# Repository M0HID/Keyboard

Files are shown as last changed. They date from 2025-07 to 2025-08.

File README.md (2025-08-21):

# K75 - A lightweight, 75% mechanical keyboard

This is a 75% keyboard fully designed by me, including the PCB, case, and firmware. It is designed to use _KMK_, a circuitpython-based firmware for keyboards! I included a rotary encoder, as well as a few "action" keys on the side of the keyboard which can be reprogrammed to anything you want, such as media controls, text controls, or any kind of shortcut you can think of!


### The PCB:
I wanted to create a challenge for myself, and so opted to use the simple _Xiao RP2040_ as the main MCU. This is however, quite limited in terms of I/O and so i had to make use of 2 MCP23017 io expanders! I also opted to use the QFP footprint on both of them which made things slightly easier to route, given the tight space but probably going to be really hard to solder :sob:




### The BOM:
| Item | Part # | Amount | Price [$] |
|:---:|---|---|---|
| 0402 SMD Diodes | C470745 | 82 | 0.60 |
| Akko cream yellow switches | https://www.aliexpress.com/item/1005007665996795.html | 82 | 27.52 |
| Purple Keycap Set | https://www.aliexpress.com/item/1005005622221680.html | 1 | 15.01 |
| Reverse Mount SK6812-Mini-E | C5149201 | 86 | 5.91 |
| Xiao RP2040 | 1597-102010428-ND | 1 | 4.68 |
| MCP23017 | C629439 | 2 | 3.03 |
| Mill-Max 0305 Hotswap Sockets | ED90584-ND | 164 | 31.42 |
| 3D printed case shipping | | 1 | 4.42 |
| PCB | | | 26.94 |
| PCB mounted Stabilisers | https://www.aliexpress.com/item/1005001632672798.html | 1 | 17.39 |
| Rotary Encoder | C470745 | 1 | 2.81 |
| WS2812B Led Sidelighting | | 1 | 5.53
| Total | | | 139.19 |

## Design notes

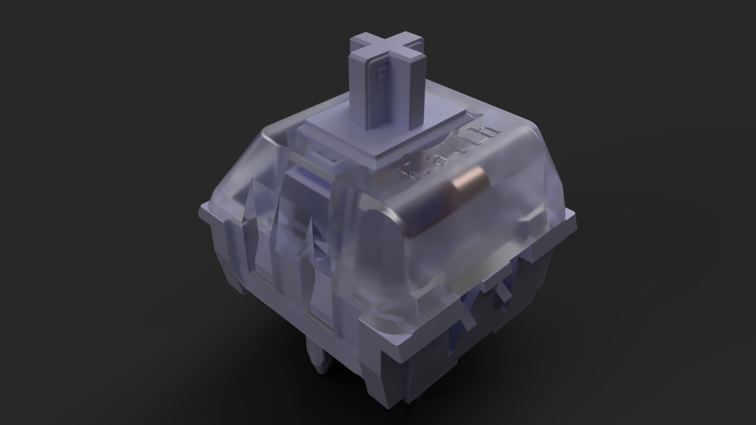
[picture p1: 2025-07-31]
pcb/kailh-polia-switch-cherry-mx-compatible-1.snapshot.1/Render.png

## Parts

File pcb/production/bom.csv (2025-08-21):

Designator | Footprint | Quantity | Value | LCSC Part #
D1, D10, D11, D12, D13, D14, D15, D16, D17, D18, D19, D2, D20, D21, D22, D23, D24, D25, D26, D27, D28, D29, D3, D30, D31, D32, D33, D34, D35, D36, D37, D38, D39, D4, D40, D41, D42, D43, D44, D45, D46, D47, D48, D49, D5, D50, D51, D52, D53, D54, D55, D56, D57, D58, D59, D6, D60, D61, D62, D63, D64, D65, D66, D67, D68, D69, D7, D70, D71, D72, D73, D74, D75, D76, D77, D78, D79, D8, D80, D81, D82, D9 | D_SOD-123 | 82 | D
D100, D101, D102, D103, D104, D105, D106, D107, D108, D109, D110, D111, D112, D113, D114, D115, D116, D117, D118, D119, D120, D121, D122, D123, D124, D125, D126, D127, D128, D129, D130, D131, D132, D133, D134, D135, D136, D137, D138, D139, D140, D141, D142, D143, D144, D145, D146, D147, D148, D149, D150, D151, D152, D153, D154, D155, D156, D157, D159, D160, D161, D162, D163, D164, D165, D166, D167, D168, D169, D83, D84, D85, D86, D87, D88, D89, D90, D91, D92, D93, D94, D95, D96, D97, D98, D99 | SK6812-MINI-E | 86 | WS2812B
SW1, SW10, SW11, SW12, SW13, SW14, SW15, SW16, SW17, SW18, SW19, SW2, SW20, SW21, SW22, SW23, SW24, SW25, SW26, SW27, SW29, SW3, SW31, SW32, SW33, SW34, SW35, SW36, SW37, SW38, SW39, SW4, SW40, SW41, SW42, SW44, SW46, SW47, SW48, SW49, SW5, SW50, SW51, SW52, SW53, SW54, SW55, SW56, SW58, SW6, SW60, SW61, SW62, SW63, SW64, SW65, SW66, SW67, SW68, SW69, SW7, SW71, SW72, SW77, SW78, SW79, SW8, SW80, SW81, SW82, SW9 | SW_Cherry_MX_1.00u_PCB | 71 | SW_Push_45deg
SW28 | SW_Cherry_MX_2.00u_PCB | 1 | SW_Push_45deg
SW30, SW43 | SW_Cherry_MX_1.50u_PCB | 2 | SW_Push_45deg
SW45, SW70 | SW_Cherry_MX_1.75u_PCB | 2 | SW_Push_45deg
SW57, SW59 | SW_Cherry_MX_2.25u_PCB | 2 | SW_Push_45deg
SW73, SW74, SW75 | SW_Cherry_MX_1.25u_PCB | 3 | SW_Push_45deg
SW76 | SW_Cherry_MX_6.25u_PCB | 1 | SW_Push_45deg
SW84 | RotaryEncoder_Alps_EC11E-Switch_Vertical_H20mm | 1 | RotaryEncoder_Switch_MP
U1 | XIAO-RP2040-DIP | 1 | MCU_Seeed_XIAO_RP2040
U2, U4 | QFN-28-1EP_6x6mm_P0.65mm_EP4.25x4.25mm | 2 | MCP23017_ML

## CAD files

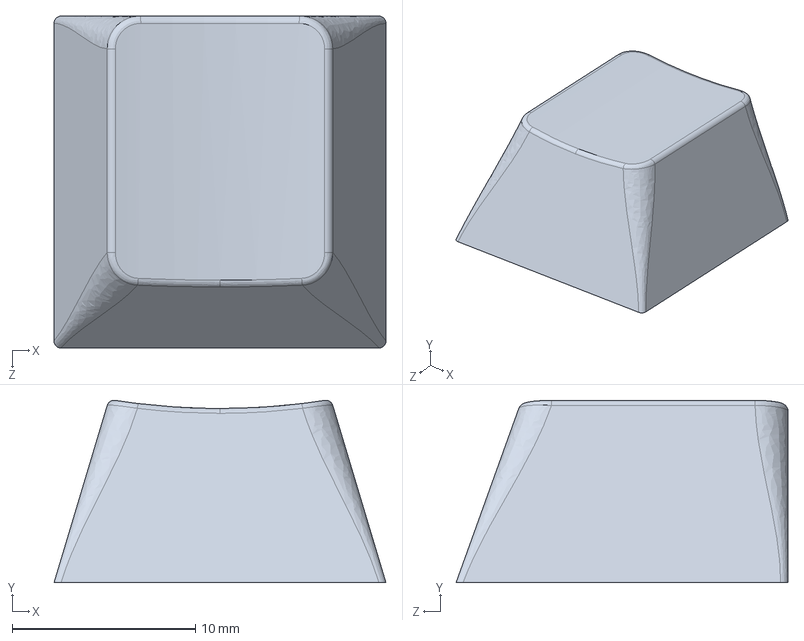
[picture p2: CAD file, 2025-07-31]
pcb/CherryMX-master/r1/r1_100.STEP
18.1 x 9.95 x 18.1 mm

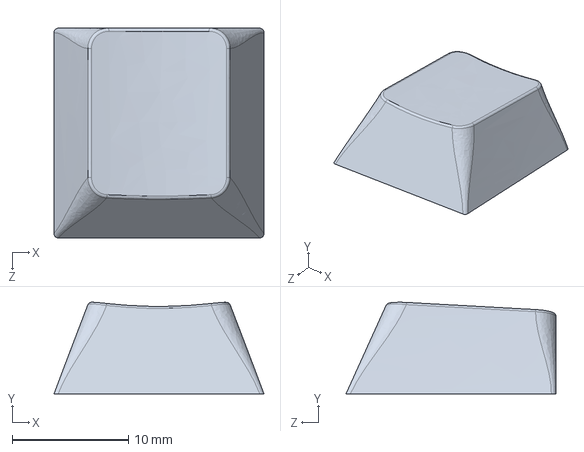
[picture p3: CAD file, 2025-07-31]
pcb/CherryMX-master/r2/r2_100.STEP
18.1 x 7.89 x 18.1 mm

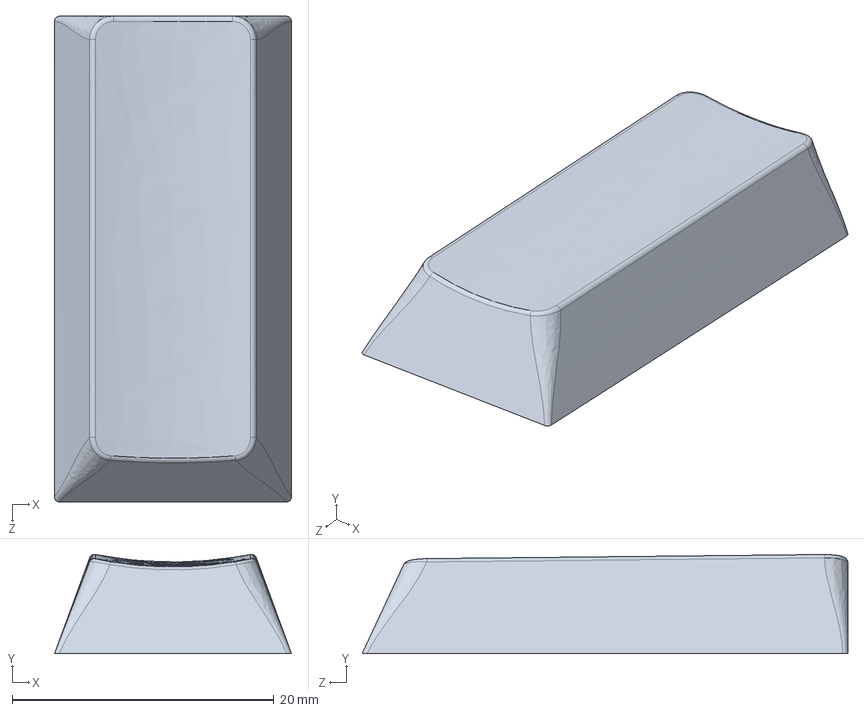
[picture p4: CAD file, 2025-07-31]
pcb/CherryMX-master/r3/r2-3_200vert.STEP
18.1 x 7.57 x 37.1 mm

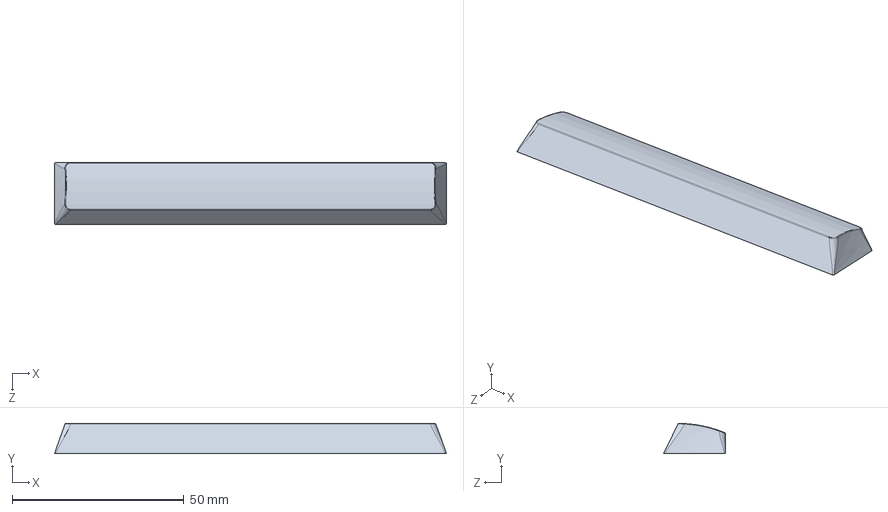
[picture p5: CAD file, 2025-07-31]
pcb/CherryMX-master/r4/r4_600.STEP
114.0 x 8.80 x 18.0 mm

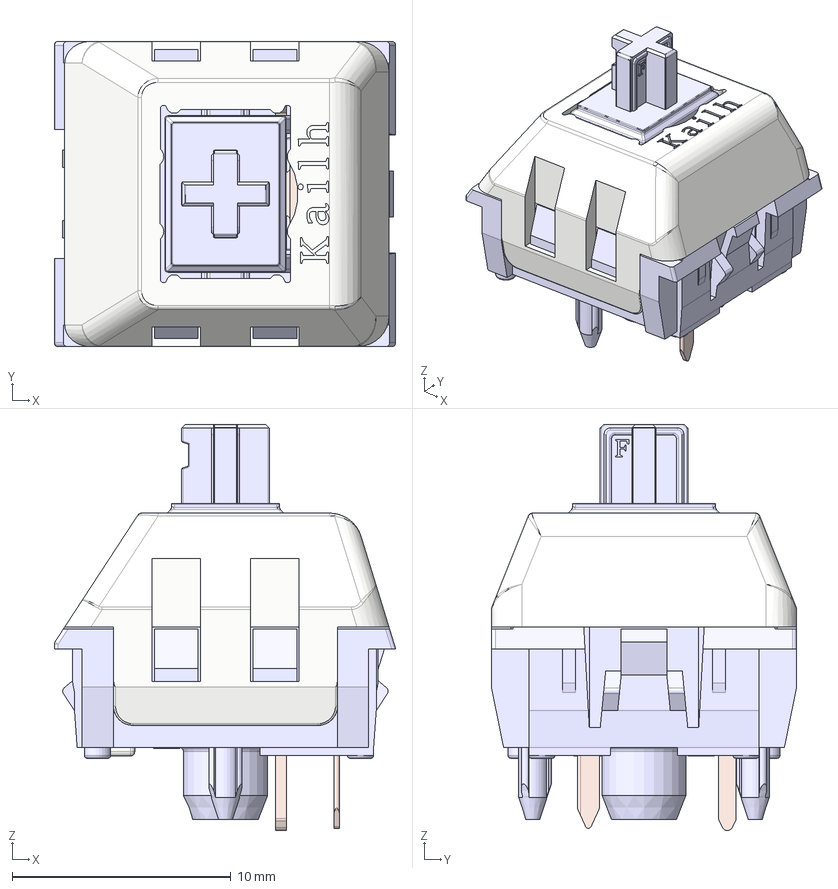
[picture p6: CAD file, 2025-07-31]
pcb/kailh-polia-switch-cherry-mx-compatible-1.snapshot.1/Kailh Polia.step
15.6 x 14.0 x 18.5 mm
Housing
ThickContact
SpringContact
Stem
Lid

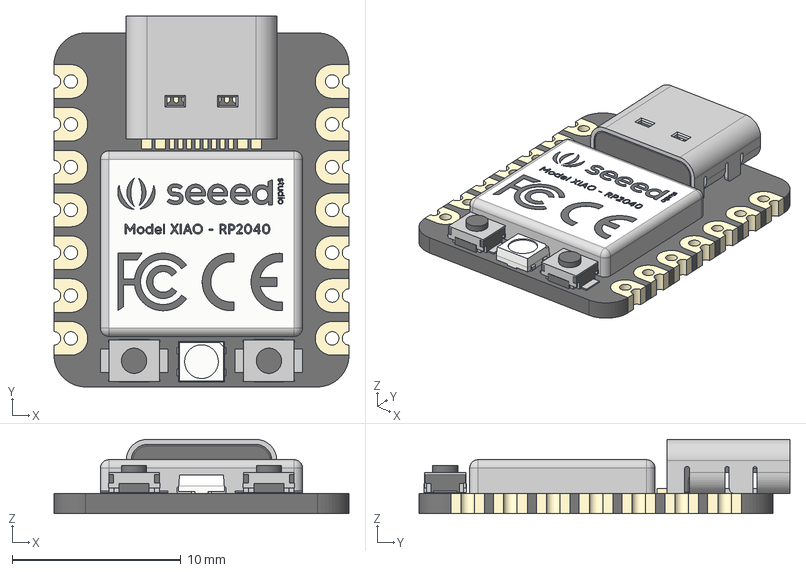
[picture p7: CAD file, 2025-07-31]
pcb/Seeed Studio XIAO RP2040 v26.step
17.5 x 22.0 x 4.40 mm
type-c v2
smd_button v3
DOUT
DIN
VSS
VDD
smd_button v3(Mirror)

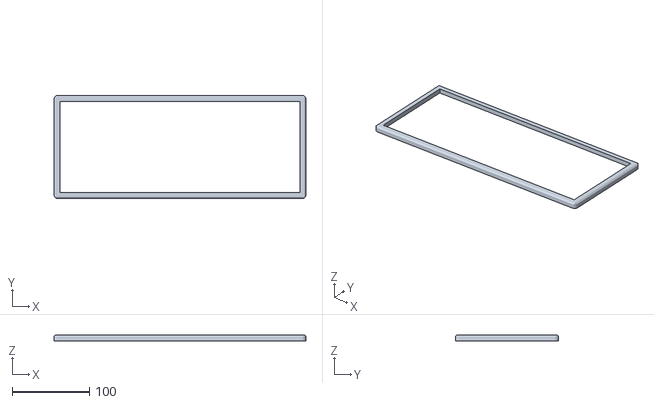
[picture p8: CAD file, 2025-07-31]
PROD/topmount.stl
326.0 x 133.6 x 7.50

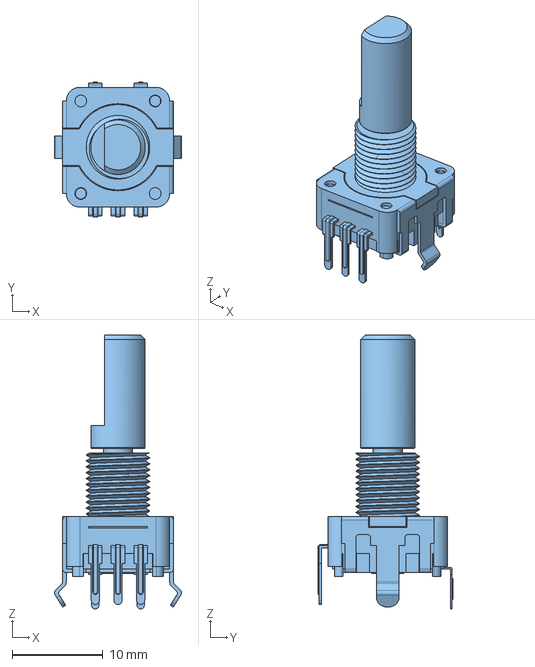
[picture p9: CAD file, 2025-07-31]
pcb/Bourns_-_PEC11R-4220F-S0024.step
14.0 x 14.9 x 30.2 mm

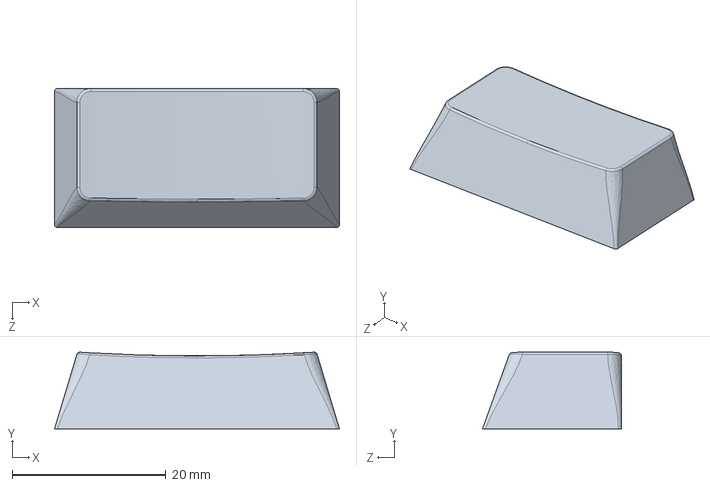
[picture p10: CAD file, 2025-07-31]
pcb/CherryMX-master/r1/r1_200.STEP
37.1 x 9.98 x 18.1 mm

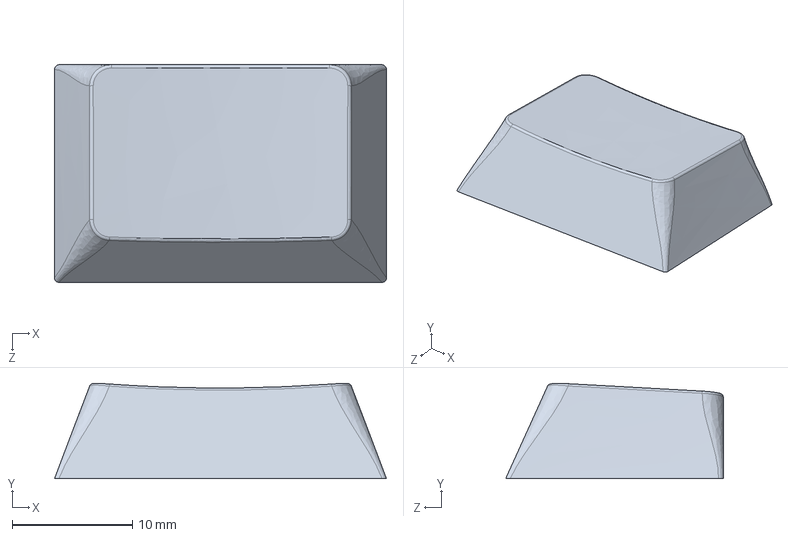
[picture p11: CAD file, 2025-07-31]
pcb/CherryMX-master/r2/r2_150.STEP
27.6 x 7.92 x 18.1 mm

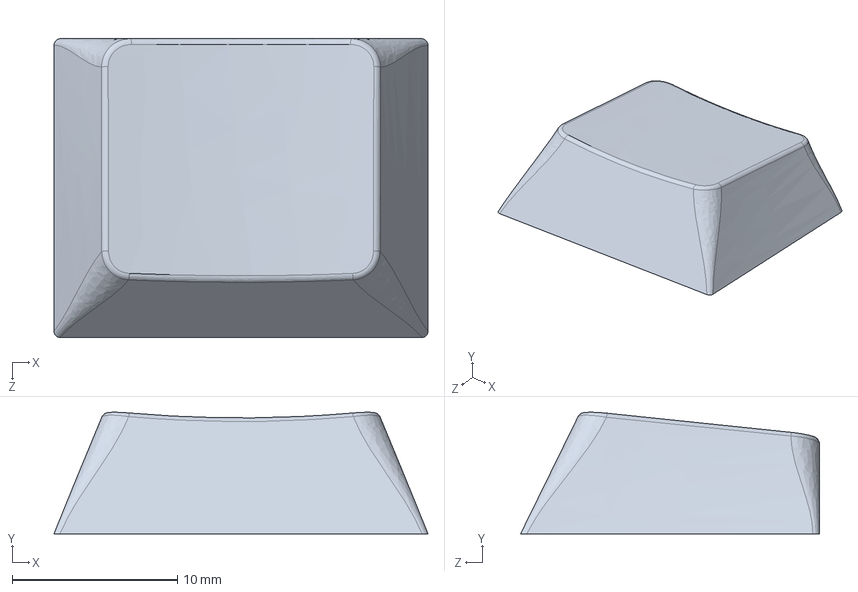
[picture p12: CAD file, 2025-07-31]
pcb/CherryMX-master/r3/r3_125.STEP
22.7 x 7.36 x 18.1 mm

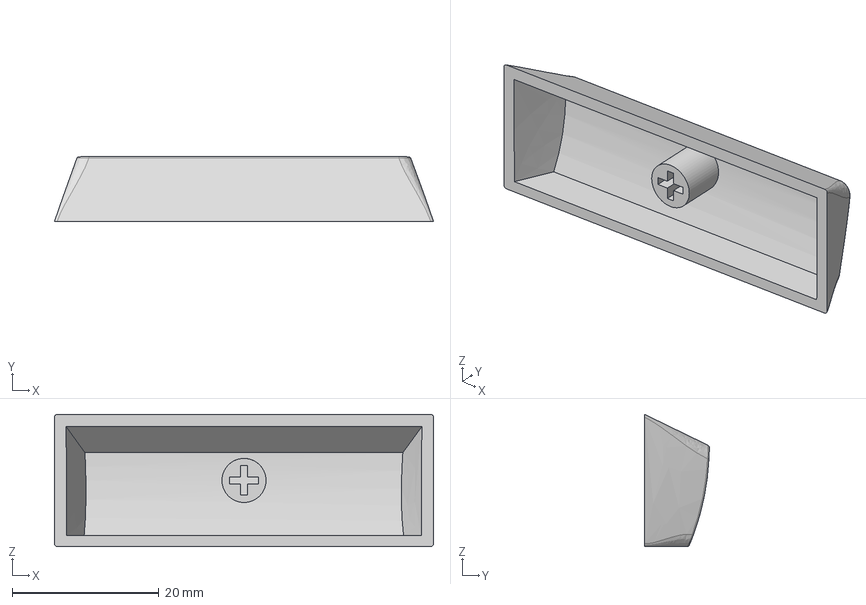
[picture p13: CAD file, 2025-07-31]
pcb/CherryMX-master/r4/r4_275C.step
51.6 x 8.80 x 18.0 mm

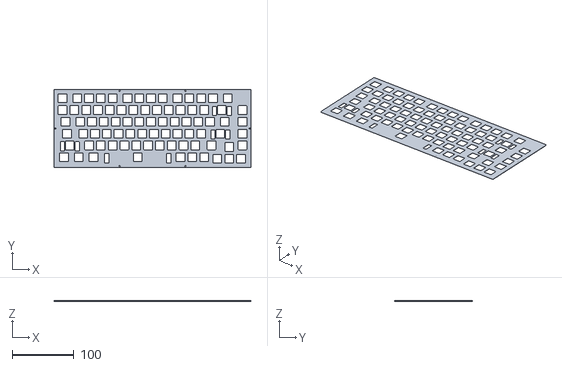
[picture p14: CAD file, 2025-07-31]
PROD/plate.stl
318.0 x 125.6 x 1.50

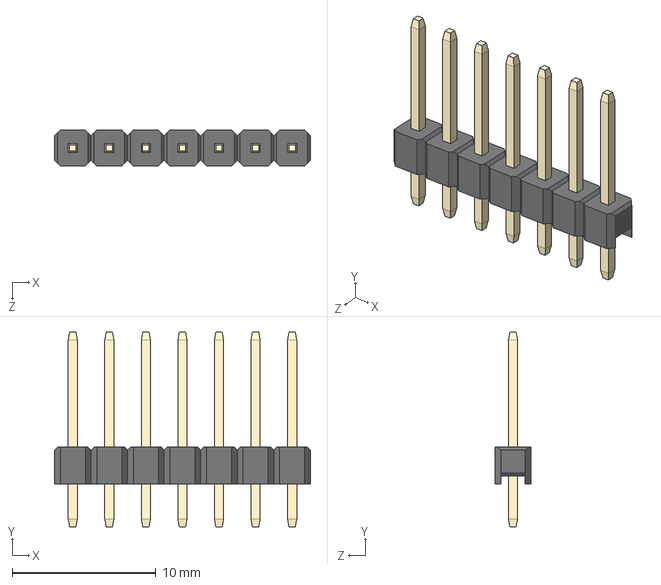
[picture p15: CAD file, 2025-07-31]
pcb/1x7 Male Pin Header.STEP
17.8 x 13.5 x 2.50 mm

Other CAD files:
pcb/CherryMX-master/r3/r3_200.STEP
pcb/CherryMX-master/r4/r4_225C.step
PROD/bottomshell.stl
pcb/CherryMX-master/r3/r3_150.STEP
pcb/CherryMX-master/r3/r3_100.STEP
pcb/CherryMX-master/r3/r3_100_bar.STEP
pcb/CherryMX-master/r3/r3_100_sculpted.STEP
pcb/CherryMX-master/r3/r3_175.STEP
pcb/CherryMX-master/r3/r3_175_stepped.STEP
pcb/CherryMX-master/r3/r3_225.STEP
pcb/CherryMX-master/r3/r3_iso.STEP
pcb/CherryMX-master/r4/r3-4_200vert.STEP
pcb/CherryMX-master/r4/r4_100.STEP
pcb/CherryMX-master/r4/r4_100C.step
pcb/CherryMX-master/r4/r4_125.STEP
pcb/CherryMX-master/r4/r4_150.STEP
pcb/CherryMX-master/r4/r4_175.STEP
pcb/CherryMX-master/r4/r4_175C.step
pcb/CherryMX-master/r4/r4_200.STEP
pcb/CherryMX-master/r4/r4_200C.step
pcb/CherryMX-master/r4/r4_225.STEP
pcb/CherryMX-master/r4/r4_275.STEP
pcb/CherryMX-master/r4/r4_300C.step
pcb/CherryMX-master/r4/r4_625.STEP
pcb/CherryMX-master/r4/r4_700.STEP

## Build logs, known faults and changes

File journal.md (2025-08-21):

---
title: "K75"
author: "@m0.hid"
description: "A 75% keyboard with per-key rgb lighting, a rotary encoder and usb-c!"
created_at: "2025-06-25"
Time Taken: 15 hours
---

### Making the schematic
Made the schematic, using 1x xiao rp2040, 1 rotary encoder, 2x i/o expanders (since the xiao itself doesnt have enough pins), and leds for each switch.
I tried doing something to make this process more automatic using hierarchal sheets but ended up just doing it all manually
Schematic:

Time += 3 hours

### Positioning all the components
Opened up the pcb editor, and put all the footprints where they're supposed to go.
I placed the xiao rp2040 underneath one of the switches on the left so it doesnt take up any extra room on the pcb. This should make it one clean board with nothing sticking out of it!  
Also i opted to use smaller 0402 smd diodes since they're smaller, hopefully i'll be able to reflow them :sob:
Started doing some of the routing as well

TIme += 2 hours

### Continue routing
I decided to modify the diode footprint a bit, so that it has a via underneath, which should hopefully make it a bit easier to route.

Finished up the rows as well

Time += 2 hours

### I/O expander
Added in one of the io expanders, underneath the enter key so it should have space to route wires to. did most of the wiring for that today.

Time += 2 hours

### the other I/O expander
Today I added in the other io expander, and started finishing up the routing. I think all the routing is done now. There wasnt much space for this one but i managed to squeeze it between the 2 function keys f4 and f5 since they have a gap between them.

Routing it was pretty difficult since there wasnt much space to fit vias or anything, so i tried re-assigning the labels in the schematic so they'd be physically closer to where they need to be 

Time += 4 hours

### Oled screen?
no

Sadly, i spent a bunch of time, trying different arrangements to fit one in, but it just wouldnt work without significant reworks (which i am not bothered to do :pray:). Maybe I'll design another kb in the future which has sone but until then, ill have to survive without one


### the 3d model!
I spent sooo long assigning the 3d models to each component, and ended up with a pretty good representation of what the kb will look like:

Time += 2 hours

And thats it for the pcb!! Moving on to the...

# the Case
Gonna try making something like this:


I made the plate using https://www.keyboard-layout-editor.com/, and then https://kbplate.ai03.com/.
Imported that in fusion, then made it 1.5mm thick and extruded the upper lip kind of thing


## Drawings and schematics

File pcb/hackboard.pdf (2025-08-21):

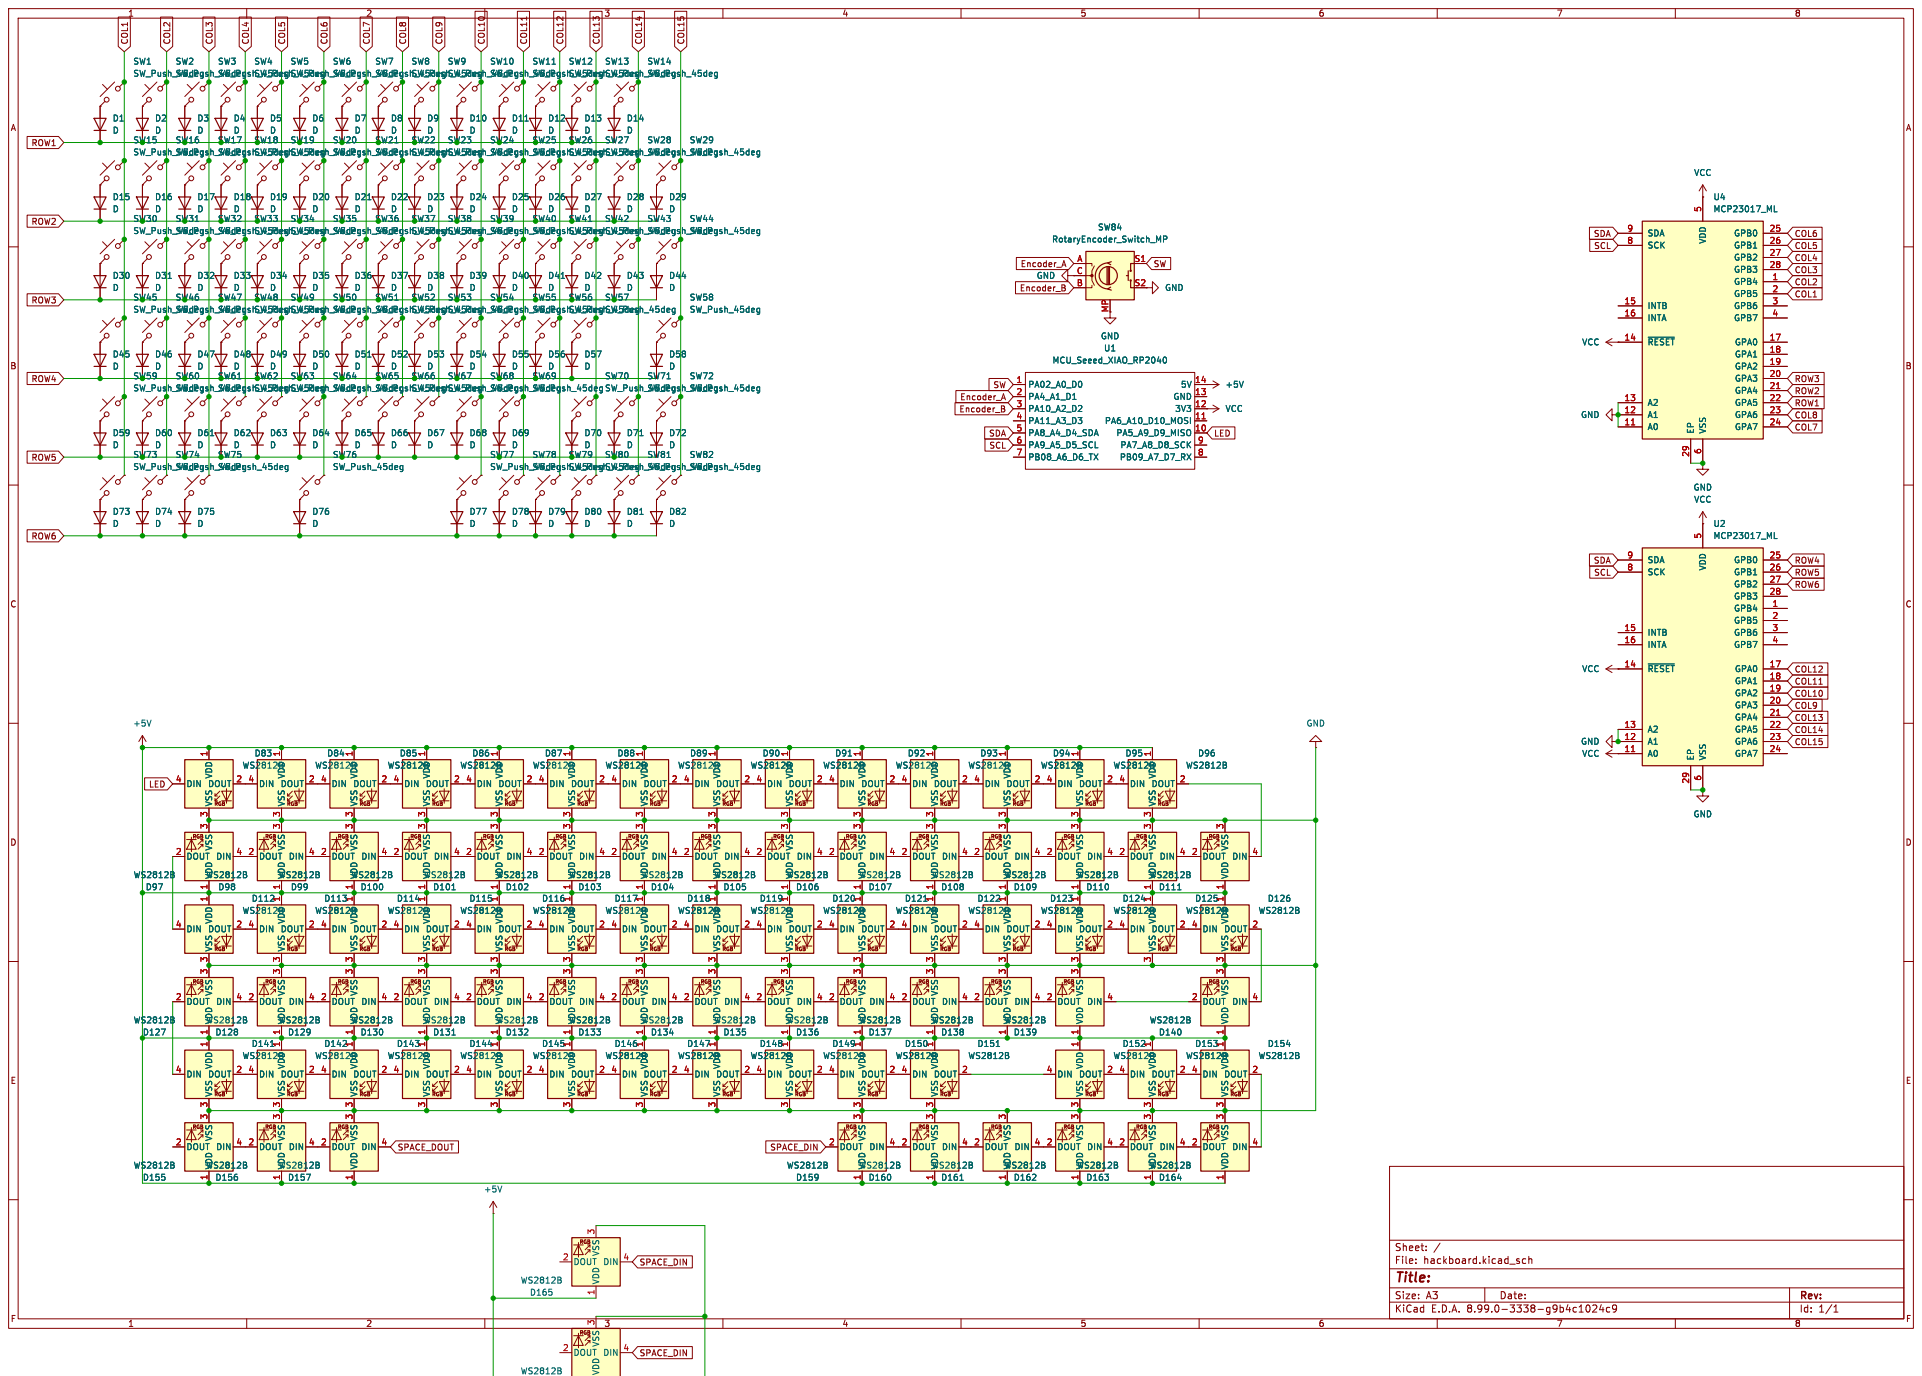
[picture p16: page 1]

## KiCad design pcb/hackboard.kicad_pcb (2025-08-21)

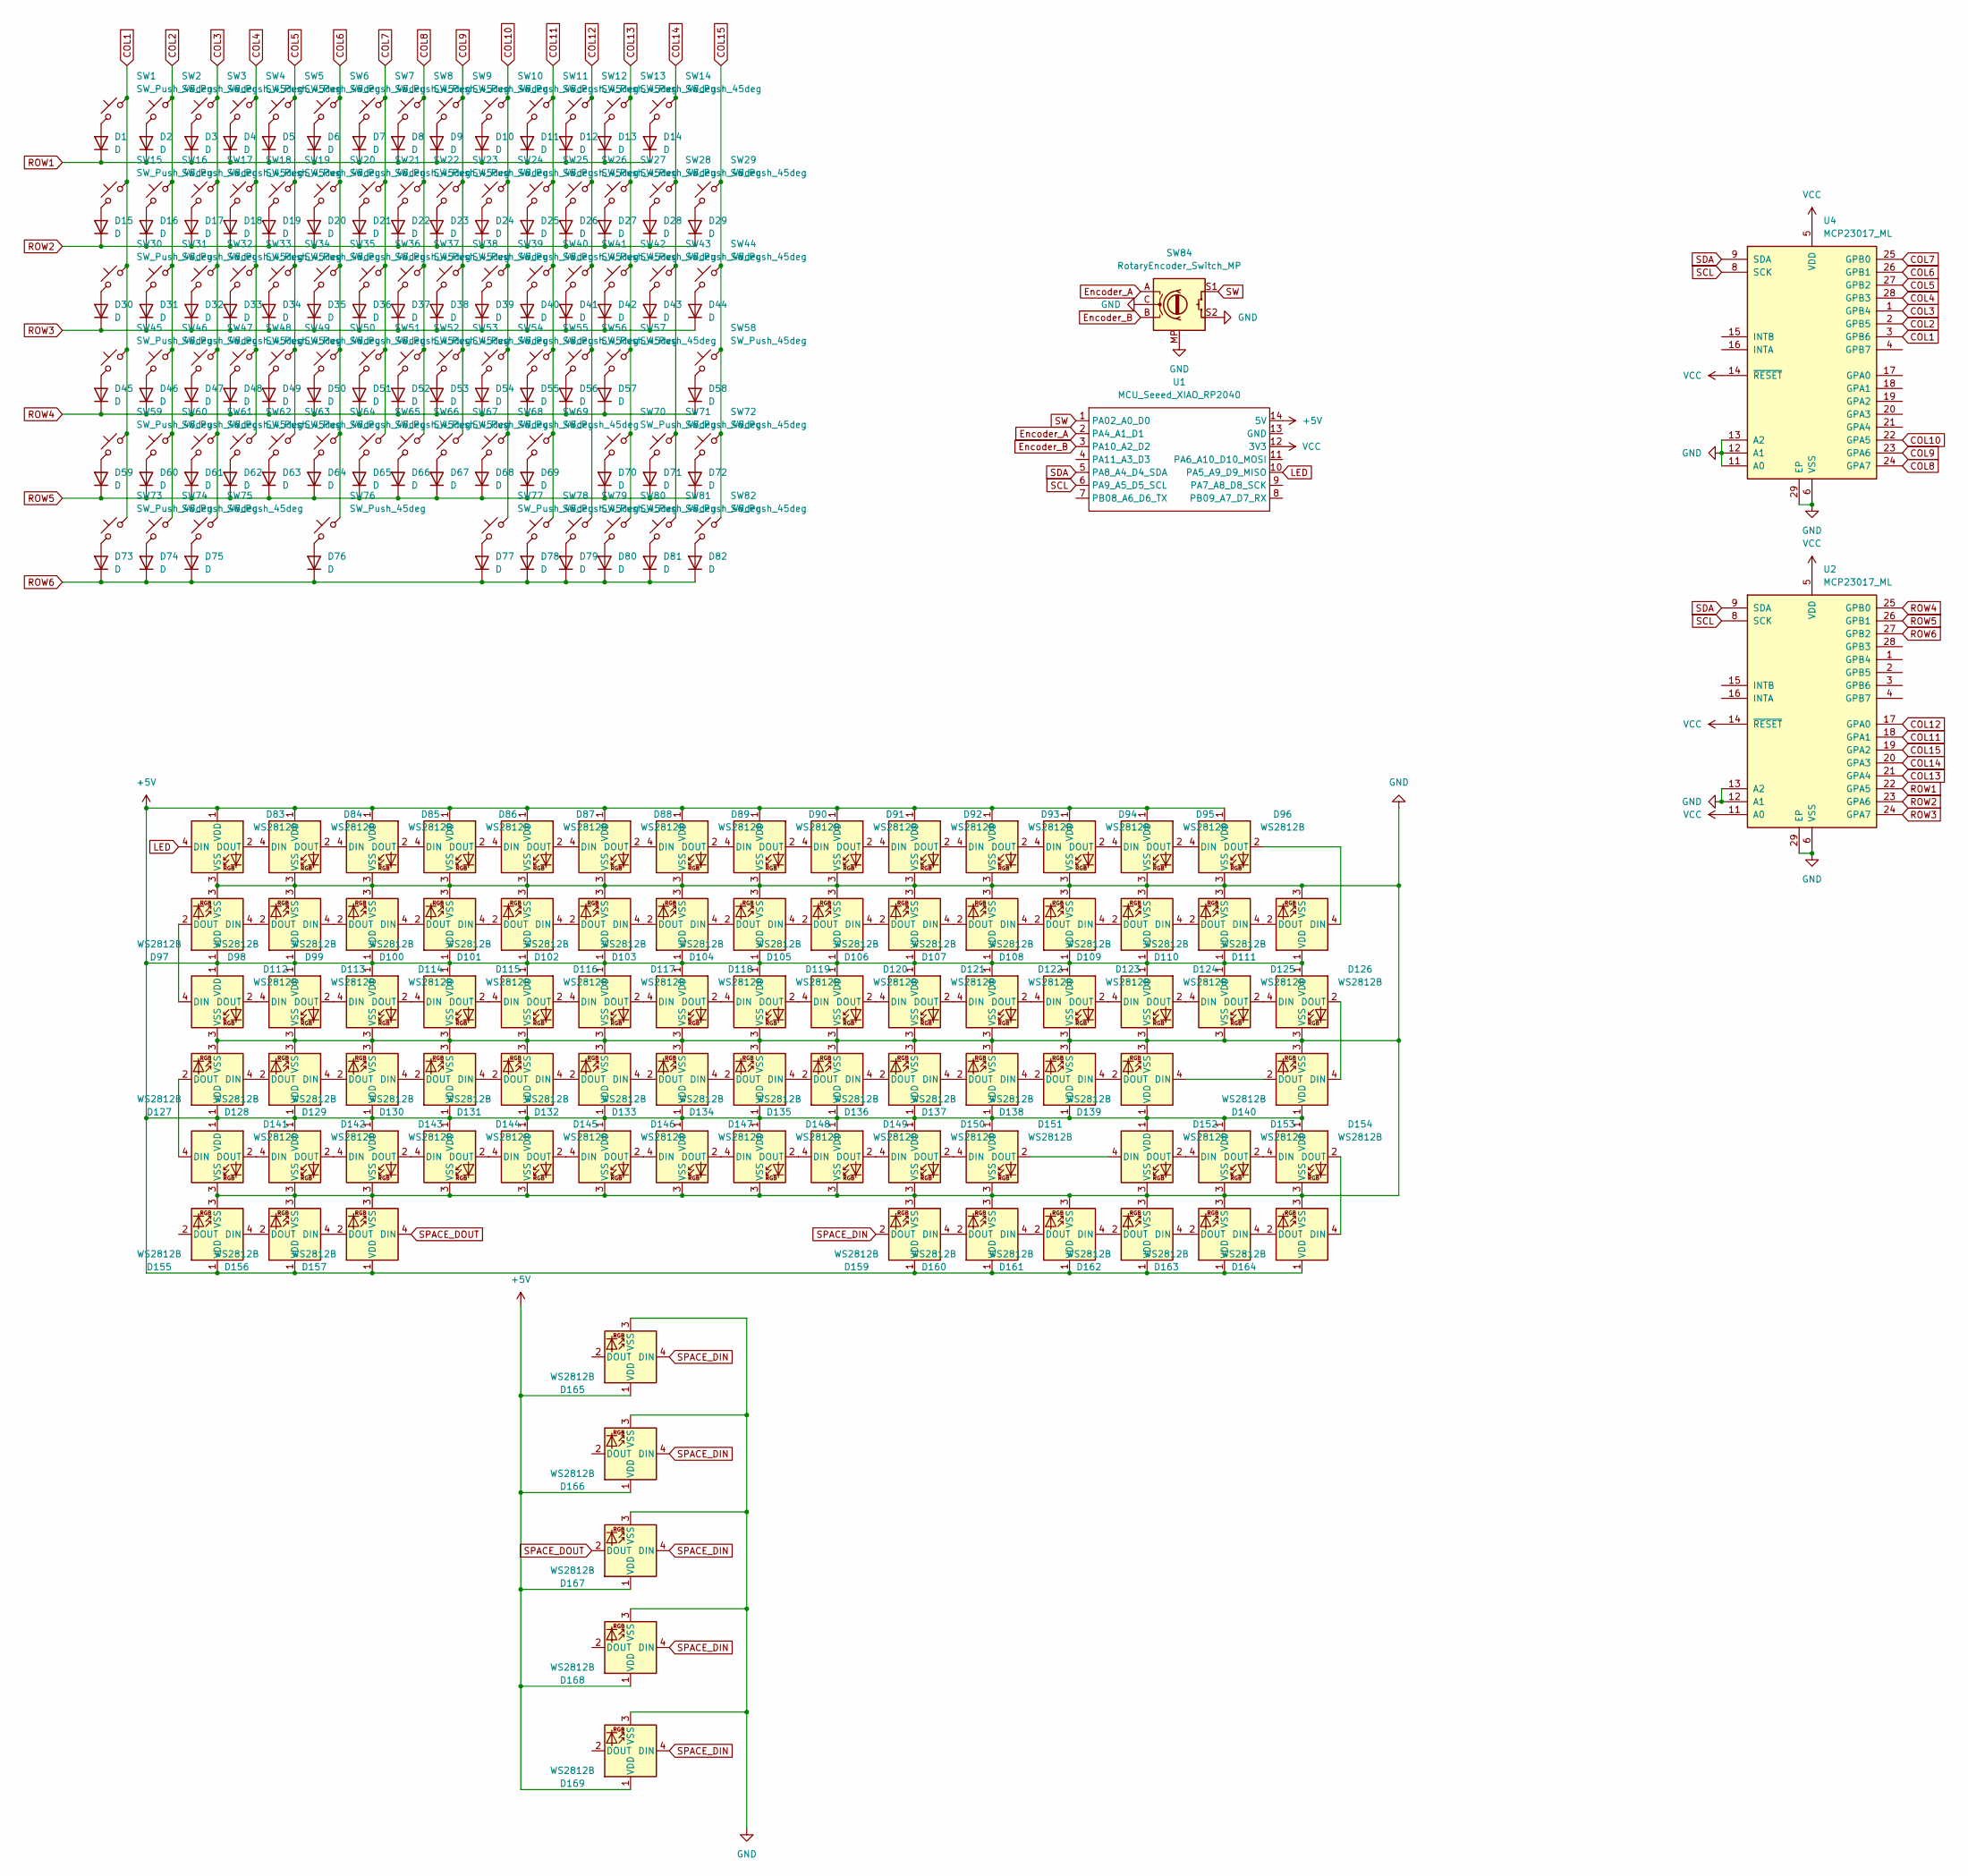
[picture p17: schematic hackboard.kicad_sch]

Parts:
D1, D2, D3, D4, D5, D6, D7, D8, D9, D10, D11, D12, D13, D14, D15, D16, D17, D18, D19, D20, D21, D22, D23, D24, D25, D26, D27, D28, D29, D30, D31, D32, D33, D34, D35, D36, D37, D38, D39, D40, D41, D42, D43, D44, D45, D46, D47, D48, D49, D50, D51, D52, D53, D54, D55, D56, D57, D58, D59, D60, D61, D62, D63, D64, D65, D66, D67, D68, D69, D70, D71, D72, D73, D74, D75, D76, D77, D78, D79, D80, D81, D82: D; D_SOD-123
D83, D84, D85, D86, D87, D88, D89, D90, D91, D92, D93, D94, D95, D96, D97, D98, D99, D100, D101, D102, D103, D104, D105, D106, D107, D108, D109, D110, D111, D112, D113, D114, D115, D116, D117, D118, D119, D120, D121, D122, D123, D124, D125, D126, D127, D128, D129, D130, D131, D132, D133, D134, D135, D136, D137, D138, D139, D140, D141, D142, D143, D144, D145, D146, D147, D148, D149, D150, D151, D152, D153, D154, D155, D156, D157, D159, D160, D161, D162, D163, D164, D165, D166, D167, D168, D169: WS2812B; SK6812-MINI-E
SW1, SW2, SW3, SW4, SW5, SW6, SW7, SW8, SW9, SW10, SW11, SW12, SW13, SW14, SW15, SW16, SW17, SW18, SW19, SW20, SW21, SW22, SW23, SW24, SW25, SW26, SW27, SW29, SW31, SW32, SW33, SW34, SW35, SW36, SW37, SW38, SW39, SW40, SW41, SW42, SW44, SW46, SW47, SW48, SW49, SW50, SW51, SW52, SW53, SW54, SW55, SW56, SW58, SW60, SW61, SW62, SW63, SW64, SW65, SW66, SW67, SW68, SW69, SW71, SW72, SW77, SW78, SW79, SW80, SW81, SW82: SW_Push_45deg; SW_Cherry_MX_1.00u_PCB
SW28: SW_Push_45deg; SW_Cherry_MX_2.00u_PCB
SW30, SW43: SW_Push_45deg; SW_Cherry_MX_1.50u_PCB
SW45, SW70: SW_Push_45deg; SW_Cherry_MX_1.75u_PCB
SW57, SW59: SW_Push_45deg; SW_Cherry_MX_2.25u_PCB
SW73, SW74, SW75: SW_Push_45deg; SW_Cherry_MX_1.25u_PCB
SW76: SW_Push_45deg; SW_Cherry_MX_6.25u_PCB
SW84: RotaryEncoder_Switch_MP; RotaryEncoder_Alps_EC11E-Switch_Vertical_H20mm
U1: MCU_Seeed_XIAO_RP2040; XIAO-RP2040-DIP
U2, U4: MCP23017_ML; QFN-28-1EP_6x6mm_P0.65mm_EP4.25x4.25mm

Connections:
+5V: D83.1 (VDD), D84.1 (VDD), D85.1 (VDD), D86.1 (VDD), D87.1 (VDD), D88.1 (VDD), D89.1 (VDD), D90.1 (VDD), D91.1 (VDD), D92.1 (VDD), D93.1 (VDD), D94.1 (VDD), D95.1 (VDD), D96.1 (VDD), D97.1 (VDD), D98.1 (VDD), D99.1 (VDD), D100.1 (VDD), D101.1 (VDD), D102.1 (VDD), D103.1 (VDD), D104.1 (VDD), D105.1 (VDD), D106.1 (VDD), D107.1 (VDD), D108.1 (VDD), D109.1 (VDD), D110.1 (VDD), D111.1 (VDD), D112.1 (VDD), D113.1 (VDD), D114.1 (VDD), D115.1 (VDD), D116.1 (VDD), D117.1 (VDD), D118.1 (VDD), D119.1 (VDD), D120.1 (VDD), D121.1 (VDD), D122.1 (VDD), D123.1 (VDD), D124.1 (VDD), D125.1 (VDD), D126.1 (VDD), D127.1 (VDD), D128.1 (VDD), D129.1 (VDD), D130.1 (VDD), D131.1 (VDD), D132.1 (VDD), D133.1 (VDD), D134.1 (VDD), D135.1 (VDD), D136.1 (VDD), D137.1 (VDD), D138.1 (VDD), D139.1 (VDD), D140.1 (VDD), D141.1 (VDD), D142.1 (VDD), D143.1 (VDD), D144.1 (VDD), D145.1 (VDD), D146.1 (VDD), D147.1 (VDD), D148.1 (VDD), D149.1 (VDD), D150.1 (VDD), D151.1 (VDD), D152.1 (VDD), D153.1 (VDD), D154.1 (VDD), D155.1 (VDD), D156.1 (VDD), D157.1 (VDD), D159.1 (VDD), D160.1 (VDD), D161.1 (VDD), D162.1 (VDD), D163.1 (VDD), D164.1 (VDD), D165.1 (VDD), D166.1 (VDD), D167.1 (VDD), D168.1 (VDD), D169.1 (VDD), U1.14 (5V)
COL1: SW1.2, SW15.2, SW30.2, SW45.2, SW59.2, SW73.2, U4.3 (GPB6)
COL2: SW2.2, SW16.2, SW31.2, SW46.2, SW60.2, SW74.2, U4.2 (GPB5)
COL3: SW3.2, SW17.2, SW32.2, SW47.2, SW61.2, SW75.2, U4.1 (GPB4)
COL4: SW4.2, SW18.2, SW33.2, SW48.2, SW62.2, U4.28 (GPB3)
COL5: SW5.2, SW19.2, SW34.2, SW49.2, SW63.2, U4.27 (GPB2)
COL6: SW6.2, SW20.2, SW35.2, SW50.2, SW64.2, SW76.2, U4.26 (GPB1)
COL7: SW7.2, SW21.2, SW36.2, SW51.2, SW65.2, U4.25 (GPB0)
COL8: SW8.2, SW22.2, SW37.2, SW52.2, SW66.2, U4.24 (GPA7)
COL9: SW9.2, SW23.2, SW38.2, SW53.2, SW67.2, U4.23 (GPA6)
COL10: SW10.2, SW24.2, SW39.2, SW54.2, SW68.2, SW77.2, U4.22 (GPA5)
COL11: SW11.2, SW25.2, SW40.2, SW55.2, SW69.2, SW78.2, U2.18 (GPA1)
COL12: SW12.2, SW26.2, SW41.2, SW56.2, SW79.2, U2.17 (GPA0)
COL13: SW13.2, SW27.2, SW42.2, SW57.2, SW70.2, SW80.2, U2.21 (GPA4)
COL14: SW14.2, SW28.2, SW43.2, SW71.2, SW81.2, U2.20 (GPA3)
COL15: SW29.2, SW44.2, SW58.2, SW72.2, SW82.2, U2.19 (GPA2)
Encoder_A: SW84.A, U1.2 (PA4_A1_D1)
Encoder_B: SW84.B, U1.3 (PA10_A2_D2)
GND: D83.3 (VSS), D84.3 (VSS), D85.3 (VSS), D86.3 (VSS), D87.3 (VSS), D88.3 (VSS), D89.3 (VSS), D90.3 (VSS), D91.3 (VSS), D92.3 (VSS), D93.3 (VSS), D94.3 (VSS), D95.3 (VSS), D96.3 (VSS), D97.3 (VSS), D98.3 (VSS), D99.3 (VSS), D100.3 (VSS), D101.3 (VSS), D102.3 (VSS), D103.3 (VSS), D104.3 (VSS), D105.3 (VSS), D106.3 (VSS), D107.3 (VSS), D108.3 (VSS), D109.3 (VSS), D110.3 (VSS), D111.3 (VSS), D112.3 (VSS), D113.3 (VSS), D114.3 (VSS), D115.3 (VSS), D116.3 (VSS), D117.3 (VSS), D118.3 (VSS), D119.3 (VSS), D120.3 (VSS), D121.3 (VSS), D122.3 (VSS), D123.3 (VSS), D124.3 (VSS), D125.3 (VSS), D126.3 (VSS), D127.3 (VSS), D128.3 (VSS), D129.3 (VSS), D130.3 (VSS), D131.3 (VSS), D132.3 (VSS), D133.3 (VSS), D134.3 (VSS), D135.3 (VSS), D136.3 (VSS), D137.3 (VSS), D138.3 (VSS), D139.3 (VSS), D140.3 (VSS), D141.3 (VSS), D142.3 (VSS), D143.3 (VSS), D144.3 (VSS), D145.3 (VSS), D146.3 (VSS), D147.3 (VSS), D148.3 (VSS), D149.3 (VSS), D150.3 (VSS), D151.3 (VSS), D152.3 (VSS), D153.3 (VSS), D154.3 (VSS), D155.3 (VSS), D156.3 (VSS), D157.3 (VSS), D159.3 (VSS), D160.3 (VSS), D161.3 (VSS), D162.3 (VSS), D163.3 (VSS), D164.3 (VSS), D165.3 (VSS), D166.3 (VSS), D167.3 (VSS), D168.3 (VSS), D169.3 (VSS), SW84.C, SW84.MP, SW84.S2, U2.6 (VSS), U2.12 (A1), U2.13 (A2), U2.29 (EP), U4.6 (VSS), U4.11 (A0), U4.12 (A1), U4.13 (A2), U4.29 (EP)
LED: D83.4 (DIN), U1.10 (PA5_A9_D9_MISO)
unnamed: D1.2 (A), SW1.1
unnamed: D2.2 (A), SW2.1
unnamed: D3.2 (A), SW3.1
unnamed: D4.2 (A), SW4.1
unnamed: D5.2 (A), SW5.1
unnamed: D6.2 (A), SW6.1
unnamed: D7.2 (A), SW7.1
unnamed: D8.2 (A), SW8.1
unnamed: D9.2 (A), SW9.1
unnamed: D10.2 (A), SW10.1
unnamed: D11.2 (A), SW11.1
unnamed: D12.2 (A), SW12.1
unnamed: D13.2 (A), SW13.1
unnamed: D14.2 (A), SW14.1
unnamed: D15.2 (A), SW15.1
unnamed: D16.2 (A), SW16.1
unnamed: D17.2 (A), SW17.1
unnamed: D18.2 (A), SW18.1
unnamed: D19.2 (A), SW19.1
unnamed: D20.2 (A), SW20.1
unnamed: D21.2 (A), SW21.1
unnamed: D22.2 (A), SW22.1
unnamed: D23.2 (A), SW23.1
unnamed: D24.2 (A), SW24.1
unnamed: D25.2 (A), SW25.1
unnamed: D26.2 (A), SW26.1
unnamed: D27.2 (A), SW27.1
unnamed: D28.2 (A), SW28.1
unnamed: D29.2 (A), SW29.1
unnamed: D30.2 (A), SW30.1
unnamed: D31.2 (A), SW31.1
unnamed: D32.2 (A), SW32.1
unnamed: D33.2 (A), SW33.1
unnamed: D34.2 (A), SW34.1
unnamed: D35.2 (A), SW35.1
unnamed: D36.2 (A), SW36.1
unnamed: D37.2 (A), SW37.1
unnamed: D38.2 (A), SW38.1
unnamed: D39.2 (A), SW39.1
unnamed: D40.2 (A), SW40.1
unnamed: D41.2 (A), SW41.1
unnamed: D42.2 (A), SW42.1
unnamed: D43.2 (A), SW43.1
unnamed: D44.2 (A), SW44.1
unnamed: D45.2 (A), SW45.1
unnamed: D46.2 (A), SW46.1
unnamed: D47.2 (A), SW47.1
unnamed: D48.2 (A), SW48.1
unnamed: D49.2 (A), SW49.1
unnamed: D50.2 (A), SW50.1
unnamed: D51.2 (A), SW51.1
unnamed: D52.2 (A), SW52.1
unnamed: D53.2 (A), SW53.1
unnamed: D54.2 (A), SW54.1
unnamed: D55.2 (A), SW55.1
unnamed: D56.2 (A), SW56.1
unnamed: D57.2 (A), SW57.1
unnamed: D58.2 (A), SW58.1
unnamed: D59.2 (A), SW59.1
unnamed: D60.2 (A), SW60.1
unnamed: D61.2 (A), SW61.1
unnamed: D62.2 (A), SW62.1
unnamed: D63.2 (A), SW63.1
unnamed: D64.2 (A), SW64.1
unnamed: D65.2 (A), SW65.1
unnamed: D66.2 (A), SW66.1
unnamed: D67.2 (A), SW67.1
unnamed: D68.2 (A), SW68.1
unnamed: D69.2 (A), SW69.1
unnamed: D70.2 (A), SW70.1
unnamed: D71.2 (A), SW71.1
unnamed: D72.2 (A), SW72.1
unnamed: D73.2 (A), SW73.1
unnamed: D74.2 (A), SW74.1
unnamed: D75.2 (A), SW75.1
unnamed: D76.2 (A), SW76.1
unnamed: D77.2 (A), SW77.1
unnamed: D78.2 (A), SW78.1
unnamed: D79.2 (A), SW79.1
unnamed: D80.2 (A), SW80.1
unnamed: D81.2 (A), SW81.1
unnamed: D82.2 (A), SW82.1
unnamed: D83.2 (DOUT), D84.4 (DIN)
unnamed: D84.2 (DOUT), D85.4 (DIN)
unnamed: D85.2 (DOUT), D86.4 (DIN)
unnamed: D86.2 (DOUT), D87.4 (DIN)
unnamed: D87.2 (DOUT), D88.4 (DIN)
unnamed: D88.2 (DOUT), D89.4 (DIN)
unnamed: D89.2 (DOUT), D90.4 (DIN)
unnamed: D90.2 (DOUT), D91.4 (DIN)
unnamed: D91.2 (DOUT), D92.4 (DIN)
unnamed: D92.2 (DOUT), D93.4 (DIN)
unnamed: D93.2 (DOUT), D94.4 (DIN)
unnamed: D94.2 (DOUT), D95.4 (DIN)
unnamed: D95.2 (DOUT), D96.4 (DIN)
unnamed: D97.4 (DIN), D98.2 (DOUT)
unnamed: D98.4 (DIN), D99.2 (DOUT)
unnamed: D100.4 (DIN), D101.2 (DOUT)
unnamed: D99.4 (DIN), D100.2 (DOUT)
unnamed: D101.4 (DIN), D102.2 (DOUT)
unnamed: D102.4 (DIN), D103.2 (DOUT)
unnamed: D103.4 (DIN), D104.2 (DOUT)
unnamed: D104.4 (DIN), D105.2 (DOUT)
unnamed: D105.4 (DIN), D106.2 (DOUT)
unnamed: D106.4 (DIN), D107.2 (DOUT)
unnamed: D107.4 (DIN), D108.2 (DOUT)
unnamed: D108.4 (DIN), D109.2 (DOUT)
unnamed: D109.4 (DIN), D110.2 (DOUT)
unnamed: D110.4 (DIN), D111.2 (DOUT)
unnamed: D96.2 (DOUT), D111.4 (DIN)
unnamed: D97.2 (DOUT), D112.4 (DIN)
unnamed: D112.2 (DOUT), D113.4 (DIN)
unnamed: D113.2 (DOUT), D114.4 (DIN)
unnamed: D114.2 (DOUT), D115.4 (DIN)
unnamed: D115.2 (DOUT), D116.4 (DIN)
unnamed: D116.2 (DOUT), D117.4 (DIN)
unnamed: D117.2 (DOUT), D118.4 (DIN)
unnamed: D118.2 (DOUT), D119.4 (DIN)
unnamed: D119.2 (DOUT), D120.4 (DIN)
unnamed: D120.2 (DOUT), D121.4 (DIN)
unnamed: D121.2 (DOUT), D122.4 (DIN)
unnamed: D122.2 (DOUT), D123.4 (DIN)
unnamed: D123.2 (DOUT), D124.4 (DIN)
unnamed: D124.2 (DOUT), D125.4 (DIN)
unnamed: D125.2 (DOUT), D126.4 (DIN)
unnamed: D126.2 (DOUT), D140.4 (DIN)
unnamed: D127.4 (DIN), D128.2 (DOUT)
unnamed: D127.2 (DOUT), D141.4 (DIN)
unnamed: D128.4 (DIN), D129.2 (DOUT)
unnamed: D129.4 (DIN), D130.2 (DOUT)
unnamed: D130.4 (DIN), D131.2 (DOUT)
unnamed: D131.4 (DIN), D132.2 (DOUT)
unnamed: D132.4 (DIN), D133.2 (DOUT)
unnamed: D133.4 (DIN), D134.2 (DOUT)
unnamed: D134.4 (DIN), D135.2 (DOUT)
unnamed: D135.4 (DIN), D136.2 (DOUT)
unnamed: D136.4 (DIN), D137.2 (DOUT)
unnamed: D137.4 (DIN), D138.2 (DOUT)
unnamed: D138.4 (DIN), D139.2 (DOUT)
unnamed: D139.4 (DIN), D140.2 (DOUT)
unnamed: D141.2 (DOUT), D142.4 (DIN)
unnamed: D142.2 (DOUT), D143.4 (DIN)
unnamed: D143.2 (DOUT), D144.4 (DIN)
unnamed: D144.2 (DOUT), D145.4 (DIN)
unnamed: D145.2 (DOUT), D146.4 (DIN)
unnamed: D146.2 (DOUT), D147.4 (DIN)
unnamed: D147.2 (DOUT), D148.4 (DIN)
unnamed: D148.2 (DOUT), D149.4 (DIN)
unnamed: D149.2 (DOUT), D150.4 (DIN)
unnamed: D150.2 (DOUT), D151.4 (DIN)
unnamed: D151.2 (DOUT), D152.4 (DIN)
unnamed: D152.2 (DOUT), D153.4 (DIN)
unnamed: D153.2 (DOUT), D154.4 (DIN)
unnamed: D154.2 (DOUT), D164.4 (DIN)
unnamed: D155.4 (DIN), D156.2 (DOUT)
unnamed: D156.4 (DIN), D157.2 (DOUT)
unnamed: D159.4 (DIN), D160.2 (DOUT)
unnamed: D160.4 (DIN), D161.2 (DOUT)
unnamed: D161.4 (DIN), D162.2 (DOUT)
unnamed: D162.4 (DIN), D163.2 (DOUT)
unnamed: D163.4 (DIN), D164.2 (DOUT)
ROW1: D1.1 (K), D2.1 (K), D3.1 (K), D4.1 (K), D5.1 (K), D6.1 (K), D7.1 (K), D8.1 (K), D9.1 (K), D10.1 (K), D11.1 (K), D12.1 (K), D13.1 (K), D14.1 (K), U2.22 (GPA5)
ROW2: D15.1 (K), D16.1 (K), D17.1 (K), D18.1 (K), D19.1 (K), D20.1 (K), D21.1 (K), D22.1 (K), D23.1 (K), D24.1 (K), D25.1 (K), D26.1 (K), D27.1 (K), D28.1 (K), D29.1 (K), U2.23 (GPA6)
ROW3: D30.1 (K), D31.1 (K), D32.1 (K), D33.1 (K), D34.1 (K), D35.1 (K), D36.1 (K), D37.1 (K), D38.1 (K), D39.1 (K), D40.1 (K), D41.1 (K), D42.1 (K), D43.1 (K), D44.1 (K), U2.24 (GPA7)
ROW4: D45.1 (K), D46.1 (K), D47.1 (K), D48.1 (K), D49.1 (K), D50.1 (K), D51.1 (K), D52.1 (K), D53.1 (K), D54.1 (K), D55.1 (K), D56.1 (K), D57.1 (K), D58.1 (K), U2.25 (GPB0)
ROW5: D59.1 (K), D60.1 (K), D61.1 (K), D62.1 (K), D63.1 (K), D64.1 (K), D65.1 (K), D66.1 (K), D67.1 (K), D68.1 (K), D69.1 (K), D70.1 (K), D71.1 (K), D72.1 (K), U2.26 (GPB1)
ROW6: D73.1 (K), D74.1 (K), D75.1 (K), D76.1 (K), D77.1 (K), D78.1 (K), D79.1 (K), D80.1 (K), D81.1 (K), D82.1 (K), U2.27 (GPB2)
SCL: U1.6 (PA9_A5_D5_SCL), U2.8 (SCK), U4.8 (SCK)
SDA: U1.5 (PA8_A4_D4_SDA), U2.9 (SDA), U4.9 (SDA)
SPACE_DIN: D159.2 (DOUT), D165.4 (DIN), D166.4 (DIN), D167.4 (DIN), D168.4 (DIN), D169.4 (DIN)
SPACE_DOUT: D157.4 (DIN), D167.2 (DOUT)
SW: SW84.S1, U1.1 (PA02_A0_D0)
VCC: U1.12 (3V3), U2.5 (VDD), U2.11 (A0), U2.14 (~RESET), U4.5 (VDD), U4.14 (~RESET)

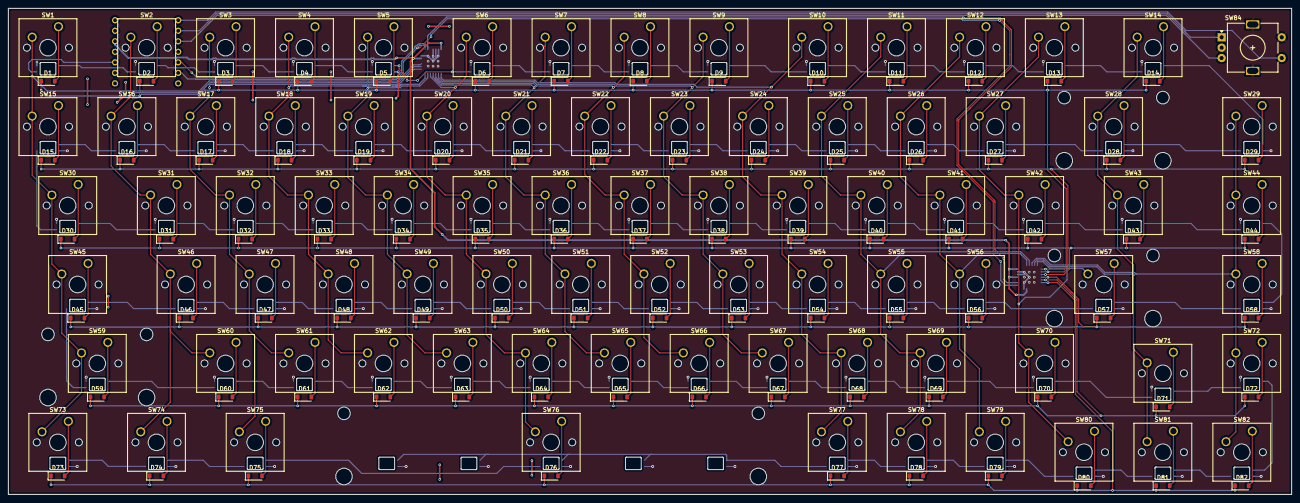
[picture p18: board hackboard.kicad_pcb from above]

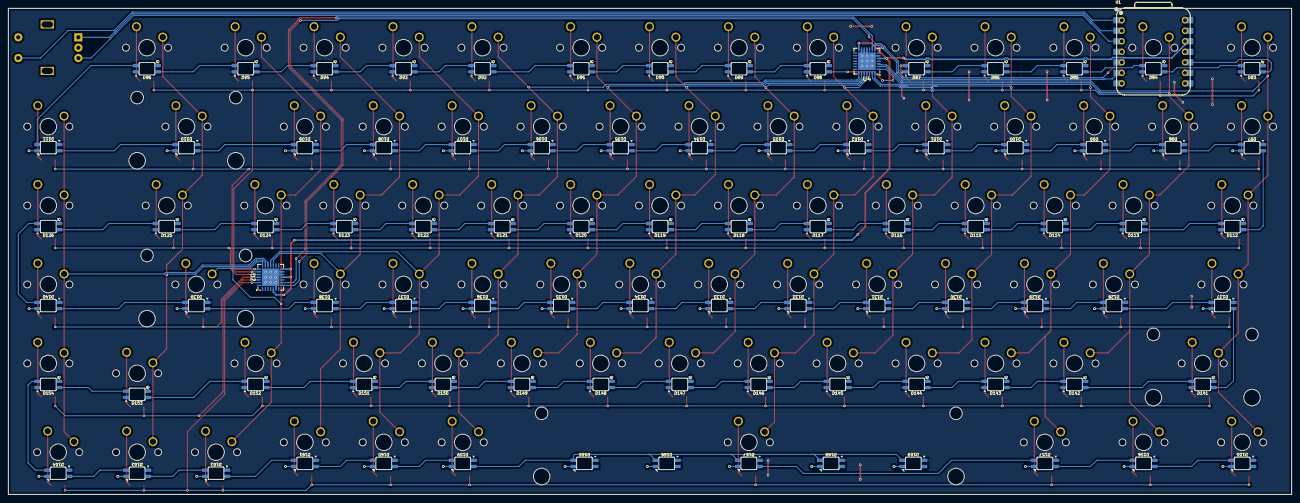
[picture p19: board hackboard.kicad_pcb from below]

Board: 2 copper layers, 309.7 x 117.3 mm, 254 parts (89 on the bottom side), 193 nets.

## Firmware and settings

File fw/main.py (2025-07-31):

from kmk.kmk_keyboard import KMKKeyboard
from kmk.scanners import DiodeOrientation
from kmk.scanners.digitalio import MatrixScanner
from kmk.scanners.keypad import KeysScanner
from kmk.keys import KC
import board
import busio
import digitalio
from adafruit_mcp230xx.mcp23017 import MCP23017
from kmk.scanners.encoder import RotaryioEncoder
from kmk.extensions.media_keys import MediaKeys
from kmk.modules.macros import Macros


class MyKeyboard(KMKKeyboard):
    def __init__(self):
        i2c = busio.I2C(board.SCL, board.SDA)
        mcp1 = MCP23017(i2c, address=0x20)
        mcp2 = MCP23017(i2c, address=0x21)

        self.row_pins = []
        for i in [0,1,2,3,4,5]:
            pin = mcp1.get_pin(i)
            self.row_pins.append(pin)

        self.col_pins = []
        for i in [6,7,8,9,10,11,12,13,14,15]:
            pin = mcp1.get_pin(i)
            self.col_pins.append(pin)
        for i in [0,1,2,3,4,5]:
            pin = mcp2.get_pin(i)
            self.col_pins.append(pin)

        super().__init__()

keyboard = MyKeyboard()

keyboard.extensions.append(MediaKeys())
macros = Macros()
keyboard.modules.append(macros)

keyboard.matrix = [
    MatrixScanner(
        cols=keyboard.col_pins,
        rows=keyboard.row_pins,
        diode_orientation=DiodeOrientation.COL2ROW,
        pull=digitalio.Pull.UP,
    ),
    RotaryioEncoder(
        pin_a=board.D7,
        pin_b=board.D8,
    ),
    KeysScanner(
        pins=[board.D6],
        value_when_pressed=False,
    )
]

keyboard.keymap = [
    [
        KC.ESC,    KC.F1,    KC.F2,    KC.F3,    KC.F4,    KC.F5,    KC.F6,    KC.F7,    KC.F8,    KC.F9,    KC.F10,   KC.F11,   KC.F12,   KC.PSCR,  KC.DEL,
        KC.GRV,    KC.N1,    KC.N2,    KC.N3,    KC.N4,    KC.N5,    KC.N6,    KC.N7,    KC.N8,    KC.N9,    KC.N0,    KC.MINS,  KC.EQL,   KC.BSPC,  KC.INS,
        KC.TAB,    KC.Q,     KC.W,     KC.E,     KC.R,     KC.T,     KC.Y,     KC.U,     KC.I,     KC.O,     KC.P,     KC.LBRC,  KC.RBRC,  KC.BSLS,  KC.HOME,
        KC.CAPS,   KC.A,     KC.S,     KC.D,     KC.F,     KC.G,     KC.H,     KC.J,     KC.K,     KC.L,     KC.SCLN,  KC.QUOT,  KC.ENT,            KC.PGUP,
        KC.LSFT,            KC.Z,     KC.X,     KC.C,     KC.V,     KC.B,     KC.N,     KC.M,     KC.COMM,  KC.DOT,   KC.SLSH,  KC.RSFT,  KC.UP,    KC.PGDN,
        KC.LCTL,   KC.LGUI,  KC.LALT,                      KC.SPC,                       KC.RALT,  KC.RGUI,  KC.MO(1), KC.LEFT,  KC.DOWN,  KC.RGHT
    ]
]

keyboard.go()

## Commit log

2025-07-31 add pcb files
    [1x7 Male Pin Header.STEP, Bourns_-_PEC11R-4220F-S0024.step, Kailh Polia.step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]
2025-08-21 update pcb
2025-08-21 modified: pcb/hackboard.kicad_pcb modified: pcb/hackboard.kicad_prl modified: pcb/hackboard.kicad_sch modified: pcb/production/bom.csv modified: pcb/production/hackboard.zip modified: pcb/production/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
    [Keeb Case v1.f3z, Keeb Case v2.step, bom.csv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]
